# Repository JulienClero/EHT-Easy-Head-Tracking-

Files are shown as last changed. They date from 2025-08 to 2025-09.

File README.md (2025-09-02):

# EHT (Easy Head Tracking)

A DIY head tracking system using ESP32 and MPU6050 for gaming and simulations, compatible with OpenTrack.

## 🎯 Features

- **3DOF Tracking**: Yaw, Pitch, Roll with gyroscope, accelerometer and magnetometer
- **WiFi Transmission**: Real-time UDP data streaming
- **Complementary Filter**: Eliminates drift on pitch/roll
- **Start Up Yaw Calibartion**: Minimizes yaw drift
- **Low Latency**: Less than 20ms end-to-end
- **OpenTrack Compatible**: Plug & play with games and simulators

## 🔧 Components

### Current Version (v1.0)
- **ESP32** (DevKit v1 or similar) - ~$8
- **MPU6050** (accelerometer + gyroscope) - ~$3
- **4 jumper wires** female-female - ~$2
- **Case/mount** (3D printing recommended) - ~$2

### Future Version (v2.0) - In Development
- **ESP32-S3 N4** - ~$3.8 (JLCPCB)
- **ICM-20948** (9-axis, accelerometer + gyroscope + magnetometer) - ~$4.5
- **EHT Custom PCB** (currently being designed)
- **Li-Ion Battery** (500-1000mAh)
- **Charging Circuit** (integrated PCB)
- **ON/OFF Switch**
- **Custom Case** (3D printed) - <$1

## 📐 Wiring Diagram

### Version v1.0 (Prototype)
```
ESP32          MPU6050
-----          -------
3.3V    ---    VCC
GND     ---    GND
GPIO21  ---    SDA
GPIO22  ---    SCL
```

### Version v2.0 (Custom PCB)
*Detailed schematic available with custom PCB*

## 🚀 Installation

### 1. Prepare Environment
```bash
# Install Arduino IDE
# Add ESP32 support:
# File > Preferences > Additional Board Manager URLs
# https://dl.espressif.com/dl/package_esp32_index.json
```

### 2. Configure Code
```cpp
// Modify these variables in the code:
const char* ssid     = "YOUR_WIFI";
const char* password = "YOUR_PASSWORD";
IPAddress pcIP(192, 168, 1, XXX);  // Your PC IP
```

### 3. Flash ESP32
- Select board: `ESP32 Dev Module`
- Select serial port
- Make modifications to the code : Fill in your wifi ssid, password and your PC's IP adress (2. Configure Code)
- Compile and upload

## 🎮 OpenTrack Configuration

### 1. Install OpenTrack
Download from: https://github.com/opentrack/opentrack/releases

### 2. Configuration
1. **Input**: `UDP over network`
   - Port: `4242`
   - Bind address: `0.0.0.0`

2. **Output**: Choose according to your game
   - `freetrack 2.0 Enhanced` (most games)
   - `TrackIR` (for compatible games)

3. **Mapping**: Adjust to your preferences

### 3. Use
- Switch on your EHT
- Stay still while it calibrates (10 sec default)
- Start OpenTrack
- Click "Start"
- You should see the octopus move with your head

## 📊 Performance

- **Frequency**: 100Hz (10ms per sample)
- **Total Latency**: < 20ms
- **Accuracy**: ±1° (pitch/roll), ±2° (yaw)
- **Drift**: None on pitch/roll, slight on yaw

## 🔧 Advanced Settings (v1.0)

### Sensitivity Adjustment
```cpp
// In code, final lines:
headData[0] = yaw * 2.0;   // Multiply for more sensitivity
headData[1] = pitch * 3.0;
headData[2] = roll * 3.0;
```

### Complementary Filter
```cpp
const float alpha = 0.99f;  // 0.95-0.99 recommended
// Closer to 1.0 = more responsive but more noise
// Closer to 0.9 = more stable but less responsive
```

## 🛠️ Troubleshooting

### WiFi Connection Issues
- Check SSID/password
- Verify ESP32 is on same network
- Restart router if necessary

### Angle Drift
- **Pitch/Roll**: No drift (complementary filter)
- **Yaw**: Normal drift without magnetometer
- Solution: Recalibrate with `Ctrl+Home` in OpenTrack

### Erratic Data
- Check I2C connections
- Add decoupling capacitors if needed
- Verify stable 3.3V power supply

### High Latency
- Reduce `LOOP_INTERVAL_MS` (watch CPU load)
- Use 5GHz WiFi if possible
- Disable WiFi sleep mode

## 🤝 Contributing

Contributions are welcome! Feel free to:
- Report bugs
- Suggest improvements
- Share hardware modifications
- Add support for more games

## 📄 License

See the `LICENSE` file for details.

## 🎮 Tested Games

- ✅ **DCS World** (freetrack)
- ✅ **Star Citizen** (freetrack)

## 🔮 Roadmap

### Version 1.0 (Current) ✅
- [x] 3DOF tracking (Yaw, Pitch, Roll)
- [x] WiFi UDP transmission
- [x] Complementary filter
- [x] Yaw Calibration
- [x] OpenTrack compatibility

### Version 2.0 (Planned)
- [ ] **EHT Custom PCB** - Compact and professional design
- [ ] **Magnetometer support** - Eliminates yaw drift
- [ ] **Integrated battery** - 8-12h autonomy
- [ ] **USB-C charging circuit** - Fast charging
- [ ] **Status LEDs or Small OLED Screen** - Battery, WiFi, tracking

---

**⚠️ Important**: This project is for personal use. Please respect the terms of use of games and simulators.

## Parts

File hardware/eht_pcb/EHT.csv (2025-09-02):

Reference | Qty | Value | DNP | Exclude from BOM | Exclude from Board | Footprint | Datasheet
BT1 | 1 | Battery_Cell |  |  |  |  | ~
C1,CIN2,COUT2 | 3 | 1uF |  |  |  | Capacitor_SMD:C_0603_1608Metric | ~
C2,CEN1,C_BP1,C_BP2,C_BP3,C_BP4,C_BP5,C_BP6,C_BP7 | 9 | 0.1uF |  |  |  | Capacitor_SMD:C_0603_1608Metric | ~
CBAT1 | 1 | 4.7uF |  |  |  | Capacitor_SMD:C_0603_1608Metric | ~
CIN1,COUT1 | 2 | 22uF |  |  |  | Capacitor_SMD:C_0603_1608Metric | ~
D1 | 1 | PTVS5V0Z1USK |  |  |  | Diode_SMD:Nexperia_DSN1608-2_1.6x0.8mm | https://assets.nexperia.com/documents/data-sheet/PTVS5V0Z1USK.pdf
D2,D3 | 2 | PESD3V3U1UL |  |  |  | Diode_SMD:D_SOD-882 | https://assets.nexperia.com/documents/data-sheet/PESD3V3U1UL.pdf
DCHG1,DPGOOD1 | 2 | LED |  |  |  | LED_SMD:LED_0805_2012Metric | ~
H1,H2,H3,H4 | 4 | MountingHole |  | Exclure de la Liste du Matériel |  | MountingHole:MountingHole_2.2mm_M2 | ~
J1 | 1 | Type-C Connector |  |  |  | Connector_USB:USB_C_Receptacle_GCT_USB4105-xx-A_16P_TopMnt_Horizontal | https://www.usb.org/sites/default/files/documents/usb_type-c.zip
R1 | 1 | R1.13k |  |  |  | Resistor_SMD:R_0603_1608Metric | ~
R2 | 1 | R1.18k |  |  |  | Resistor_SMD:R_0603_1608Metric | ~
R3 | 1 | R10k |  |  |  | Resistor_SMD:R_0603_1608Metric | ~
R4,R5,REN1 | 3 | R1k |  |  |  | Resistor_SMD:R_0603_1608Metric | ~
R_CC1,R_CC2 | 2 | R5.1k |  |  |  | Resistor_SMD:R_0603_1608Metric | ~
SW1 | 1 | SW_Push |  |  |  | Button_Switch_THT:SW_PUSH_1P1T_6x3.5mm_H4.3_APEM_MJTP1243 | ~
SW2 | 1 | SW |  |  |  | Button_Switch_SMD:SW_DIP_SPSTx01_Slide_Copal_CHS-01A_W5.08mm_P1.27mm_JPin | ~
U2 | 1 | ICM-20948 |  |  |  | Sensor_Motion:InvenSense_QFN-24_3x3mm_P0.4mm | http://www.invensense.com/wp-content/uploads/2016/06/DS-000189-ICM-20948-v1.3.pdf
U3 | 1 | BQ24074 |  |  |  | Package_DFN_QFN:VQFN-16-1EP_3x3mm_P0.5mm_EP1.6x1.6mm | http://www.ti.com/lit/ds/symlink/bq24074.pdf
U4 | 1 | TLV70019_SOT23-5 |  |  |  | Package_TO_SOT_SMD:SOT-23-5 | http://www.ti.com/lit/ds/symlink/tlv700.pdf
U5 | 1 | TXB0104D |  |  |  | Package_SO:SOIC-14_3.9x8.7mm_P1.27mm | http://www.ti.com/lit/ds/symlink/txb0104.pdf
U6 | 1 | AMS1117-3.3 |  |  |  | Package_TO_SOT_SMD:SOT-223-3_TabPin2 | http://www.advanced-monolithic.com/pdf/ds1117.pdf
U7 | 1 | ESP32-S3-WROOM-1 |  |  |  | RF_Module:ESP32-S3-WROOM-1 | https://www.espressif.com/sites/default/files/documentation/esp32-s3-wroom-1_wroom-1u_datasheet_en.pdf

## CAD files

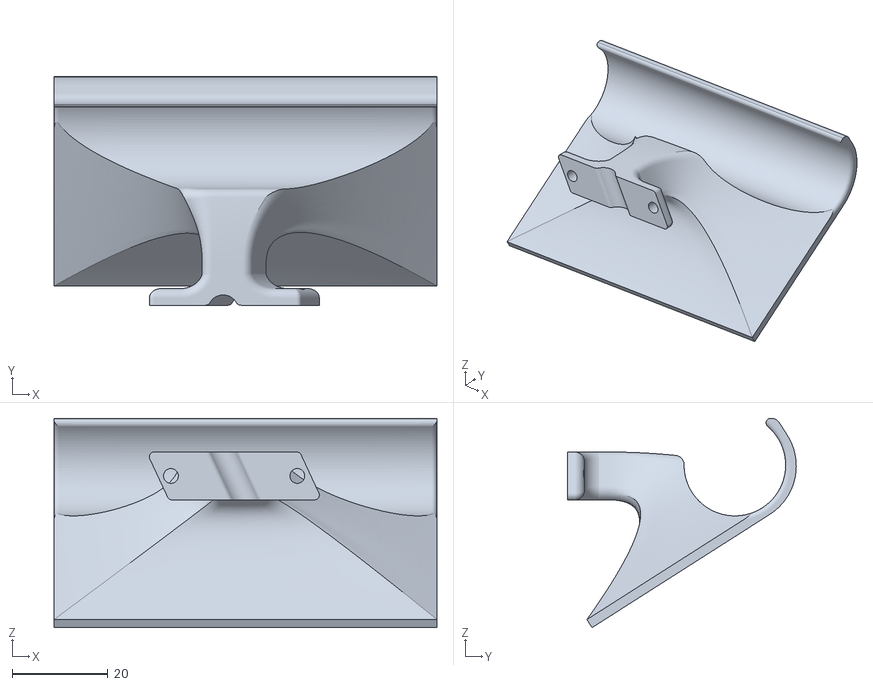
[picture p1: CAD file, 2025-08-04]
hardware/3d_models/EHT_V1_LogitechG935_Mount.stl
80.0 x 47.7 x 43.7

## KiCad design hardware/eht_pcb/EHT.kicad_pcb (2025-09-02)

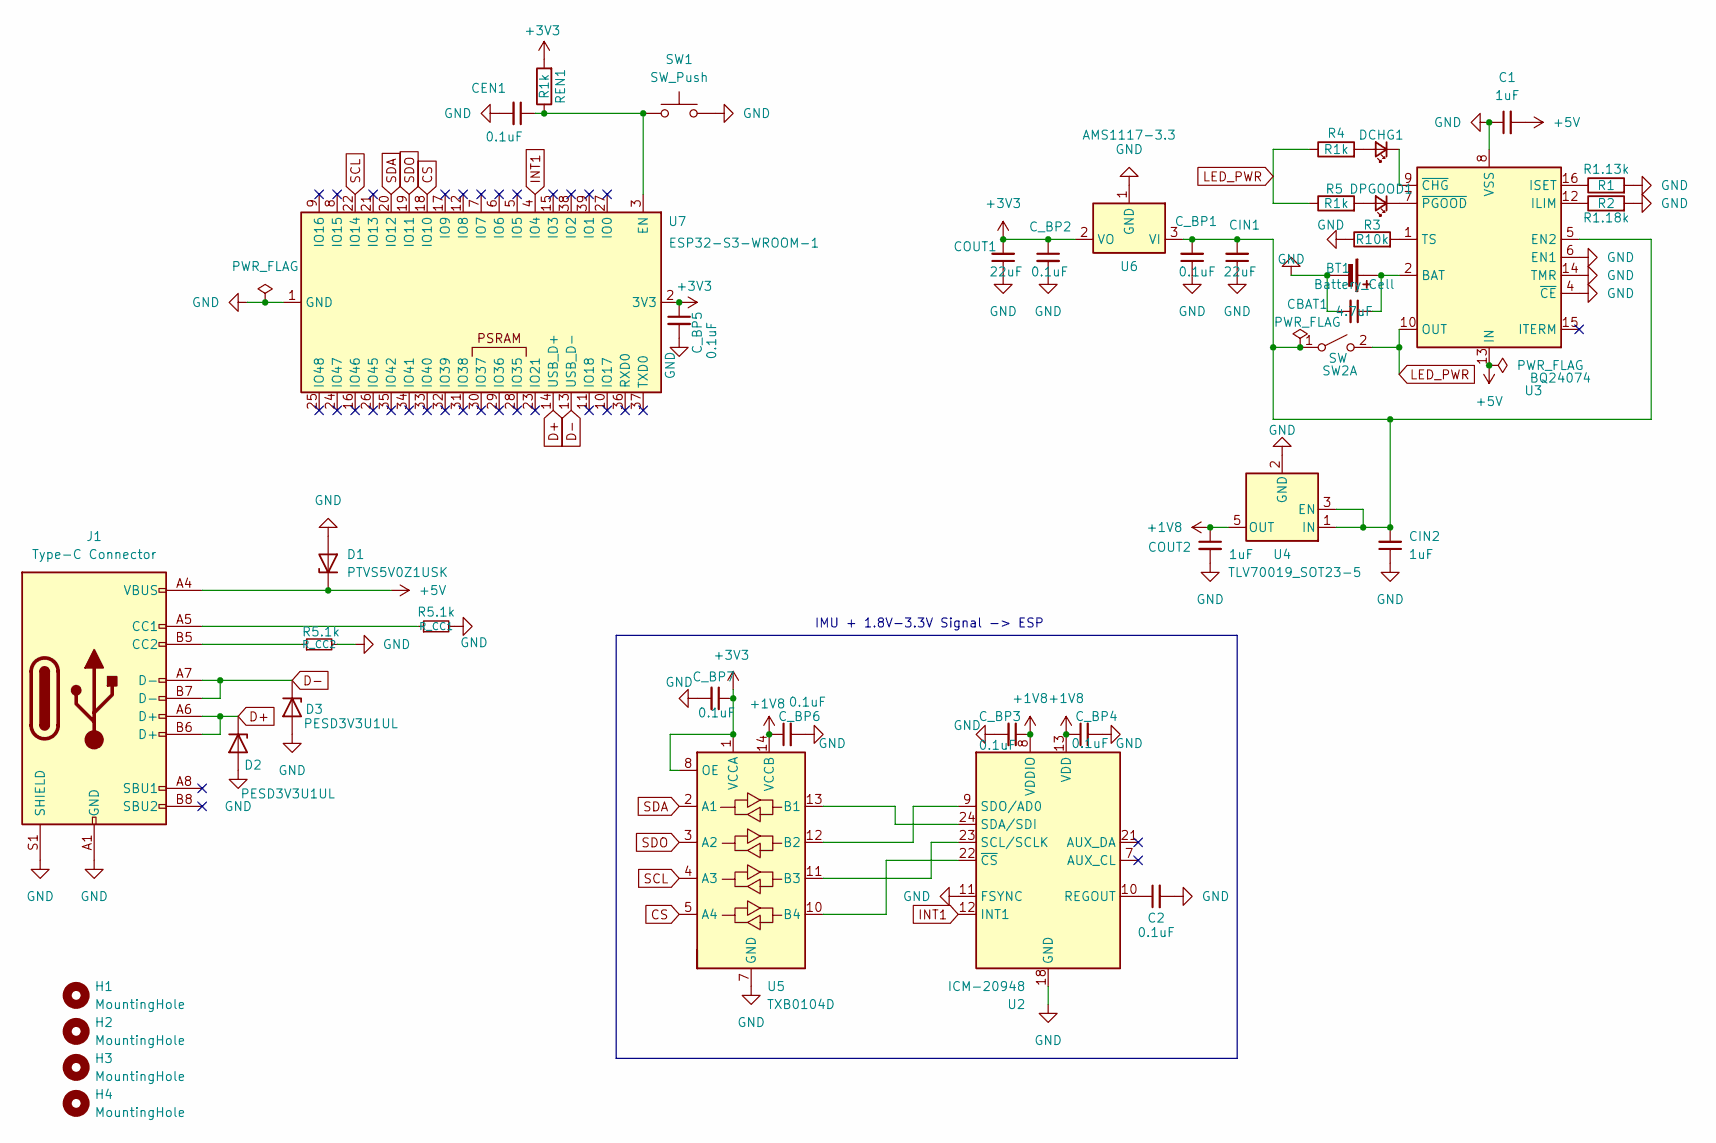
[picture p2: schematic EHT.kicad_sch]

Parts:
BT1: Battery_Cell
C1: 1uF; C_0603_1608Metric
C2: 0.1uF; C_0603_1608Metric
CBAT1: 4.7uF; C_0603_1608Metric
CEN1: 0.1uF; C_0603_1608Metric
CIN1: 22uF; C_0603_1608Metric
CIN2: 1uF; C_0603_1608Metric
COUT1: 22uF; C_0603_1608Metric
COUT2: 1uF; C_0603_1608Metric
C_BP1, C_BP2, C_BP3, C_BP4, C_BP5, C_BP6, C_BP7: 0.1uF; C_0603_1608Metric
D1: PTVS5V0Z1USK; Nexperia_DSN1608-2_1.6x0.8mm
D2, D3: PESD3V3U1UL; D_SOD-882
DCHG1: LED; LED_0805_2012Metric
DPGOOD1: LED; LED_0805_2012Metric
H1, H2, H3, H4: MountingHole; MountingHole_2.2mm_M2
J1: Type-C Connector; USB_C_Receptacle_GCT_USB4105-xx-A_16P_TopMnt_Horizontal
R1: R1.13k; R_0603_1608Metric
R2: R1.18k; R_0603_1608Metric
R3: R10k; R_0603_1608Metric
R4, R5: R1k; R_0603_1608Metric
REN1: R1k; R_0603_1608Metric
R_CC1, R_CC2: R5.1k; R_0603_1608Metric
SW1: SW_Push; SW_PUSH_1P1T_6x3.5mm_H4.3_APEM_MJTP1243
SW2: SW; SW_DIP_SPSTx01_Slide_Copal_CHS-01A_W5.08mm_P1.27mm_JPin
U2: ICM-20948; InvenSense_QFN-24_3x3mm_P0.4mm
U3: BQ24074; VQFN-16-1EP_3x3mm_P0.5mm_EP1.6x1.6mm
U4: TLV70019_SOT23-5; SOT-23-5
U5: TXB0104D; SOIC-14_3.9x8.7mm_P1.27mm
U6: AMS1117-3.3; SOT-223-3_TabPin2
U7: ESP32-S3-WROOM-1

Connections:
+1V8: COUT2.1, C_BP3.1, C_BP4.1, C_BP6.1, U2.8 (VDDIO), U2.13 (VDD), U4.5 (OUT), U5.14 (VCCB)
+3V3: COUT1.2, C_BP2.1, C_BP5.1, C_BP7.1, REN1.2, U5.1 (VCCA), U5.8 (OE), U6.2 (VO), U7.2 (3V3)
+5V: C1.2, D1.1 (K), J1.A4 (VBUS), J1.A9 (VBUS), J1.B4 (VBUS), J1.B9 (VBUS), U3.13 (IN)
CS: U5.5 (A4), U7.18 (IO10)
D+: D2.1 (K), J1.A6 (D+), J1.B6 (D+), U7.14 (USB_D+)
D-: D3.1 (K), J1.A7 (D-), J1.B7 (D-), U7.13 (USB_D-)
GND: BT1.2 (-), C1.1, C2.2, CBAT1.2, CEN1.2, CIN1.1, CIN2.1, COUT1.1, COUT2.2, C_BP1.1, C_BP2.2, C_BP3.2, C_BP4.2, C_BP5.2, C_BP6.2, C_BP7.2, D1.2 (A), D2.2 (A), D3.2 (A), J1.A1 (GND), J1.A12 (GND), J1.B1 (GND), J1.B12 (GND), J1.S1 (SHIELD), R1.2, R2.2, R3.1, R_CC1.2, R_CC2.2, SW1.2, U2.11 (FSYNC), U2.18 (GND), U2.20 (GND), U3.4 (~CE), U3.6 (EN1), U3.8 (VSS), U3.14 (TMR), U3.17 (VSS), U4.2 (GND), U5.7 (GND), U6.1 (GND), U7.1 (GND), U7.40 (GND), U7.41 (GND); also elsewhere on the board
INT1: U2.12 (INT1), U7.4 (IO4)
LED_PWR: R4.1, R5.1, SW2.2 (B), U3.10 (OUT), U3.11 (OUT)
unnamed 9: BT1.1 (+), CBAT1.1, U3.2 (BAT), U3.3 (BAT); also elsewhere on the board
unnamed: DCHG1.2 (A), R4.2
unnamed: DCHG1.1 (K), U3.9 (~CHG)
unnamed: DPGOOD1.2 (A), R5.2
unnamed: DPGOOD1.1 (K), U3.7 (~PGOOD)
unnamed: J1.A5 (CC1), R_CC1.1
unnamed: J1.B5 (CC2), R_CC2.1
unnamed: CIN1.2, CIN2.2, C_BP1.2, SW2.1 (A), U3.5 (EN2), U4.1 (IN), U4.3 (EN), U6.3 (VI)
unnamed: C2.1, U2.10 (REGOUT)
unnamed: U2.23 (SCL/SCLK), U5.11 (B3)
unnamed: U2.24 (SDA/SDI), U5.13 (B1)
unnamed: U2.9 (SDO/AD0), U5.12 (B2)
unnamed: U2.22 (~CS), U5.10 (B4)
unnamed: R2.1, U3.12 (ILIM)
unnamed: R1.1, U3.16 (ISET)
unnamed: R3.2, U3.1 (TS)
unnamed: CEN1.1, REN1.1, SW1.1, U7.3 (EN)
SCL: U5.4 (A3), U7.22 (IO14)
SDA: U5.2 (A1), U7.20 (IO12)
SDO: U5.3 (A2), U7.19 (IO11)

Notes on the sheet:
IMU + 1.8V-3.3V Signal -> ESP

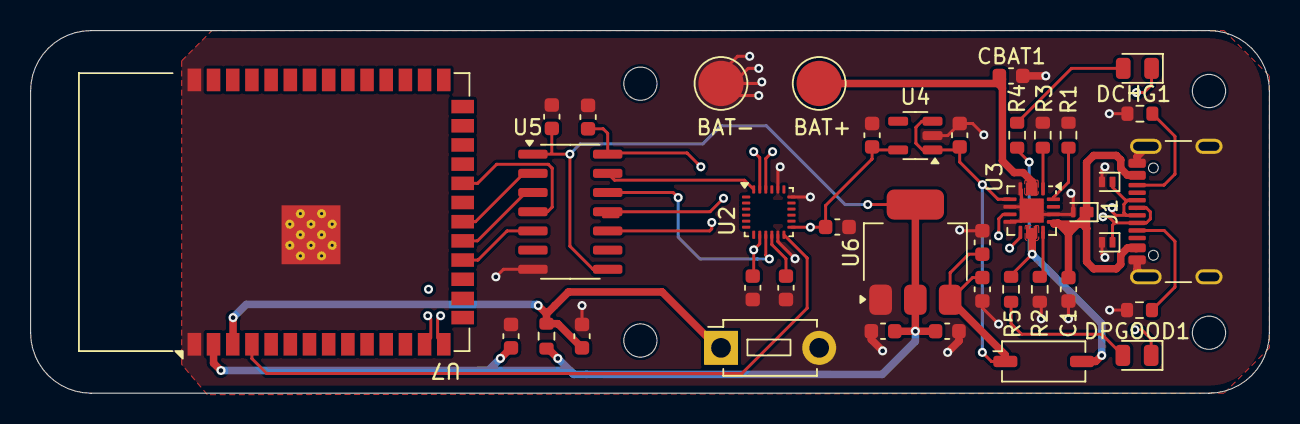
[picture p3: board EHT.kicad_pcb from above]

Board: 4 copper layers, 82.0 x 24.0 mm, 43 parts (0 on the bottom side), 29 nets.

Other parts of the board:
BAT+: TestPoint_Pad_D3.0mm
BAT-: TestPoint_Pad_D3.0mm

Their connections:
GND: BAT-.1; also elsewhere on the board
unnamed 9: BAT+.1; also elsewhere on the board

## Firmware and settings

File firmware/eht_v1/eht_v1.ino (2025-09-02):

#include <Wire.h>
#include <WiFi.h>
#include <WiFiUdp.h>

// ======= Réseau =======
const char* ssid     = "Livebox-197A";
const char* password = "62AB114F8D346586595ED49934";
IPAddress pcIP(192, 168, 1, 21);
const uint16_t pcPort   = 4242;
WiFiUDP udp;
const uint16_t localPort = 4242;

// ======= MPU6050 =======
#define MPU_ADDR       0x68
#define PWR_MGMT_1     0x6B
#define ACCEL_XOUT_H   0x3B
#define GYRO_XOUT_H    0x43

// Variables de tracking (thread-safe avec mutex)
portMUX_TYPE angleMux = portMUX_INITIALIZER_UNLOCKED;
double headData[3];
volatile float yaw = 0, pitch = 0, roll = 0;

// Paramètres du filtre complémentaire
const float alpha = 0.98f;

// Variables pour calibration automatique du drift
float drift_sum = 0.0f;
int drift_samples = 0;
float drift_correction = 0.0f;
bool calibration_complete = false;
unsigned long calibration_start = 0;
const unsigned long CALIBRATION_DURATION = 10000; // 10 secondes

// Gestion d'erreurs I2C
int i2c_error_count = 0;
const int MAX_I2C_ERRORS = 3;
bool mpu_initialized = false;

// Queue pour communication inter-core
QueueHandle_t sensorQueue;
struct SensorData {
  float ax_g, ay_g, az_g;
  float gx_dps, gy_dps, gz_dps;
  unsigned long timestamp;
};

// I2C write avec gestion d'erreur
bool writeByte(uint8_t addr, uint8_t reg, uint8_t val) {
  Wire.beginTransmission(addr);
  Wire.write(reg);
  Wire.write(val);
  uint8_t error = Wire.endTransmission();
  
  if (error != 0) {
    i2c_error_count++;
    return false;
  }
  return true;
}

// I2C read avec timeout
bool readBytes(uint8_t addr, uint8_t reg, uint8_t len, uint8_t* buf) {
  Wire.beginTransmission(addr);
  Wire.write(reg);
  if (Wire.endTransmission(false) != 0) {
    i2c_error_count++;
    return false;
  }
  
  if (Wire.requestFrom(addr, len) != len) {
    i2c_error_count++;
    return false;
  }
  
  for (uint8_t i = 0; i < len; i++) {
    buf[i] = Wire.read();
  }
  return true;
}

// Initialisation MPU6050
bool initMPU() {
  if (!writeByte(MPU_ADDR, PWR_MGMT_1, 0x80)) return false; 
  delay(50);
  if (!writeByte(MPU_ADDR, PWR_MGMT_1, 0x00)) return false; 
  delay(10);
  
  // Configuration optimisée pour la précision
  if (!writeByte(MPU_ADDR, 0x1A, 0x01)) return false; // DLPF = 188Hz
  if (!writeByte(MPU_ADDR, 0x1B, 0x00)) return false; // Gyro ±250°/s
  if (!writeByte(MPU_ADDR, 0x1C, 0x00)) return false; // Accel ±2g
  if (!writeByte(MPU_ADDR, 0x19, 0x07)) return false; // Sample rate = 125Hz
  
  return true;
}

// Réinitialisation I2C
void resetI2C() {
  Wire.end();
  delay(30);
  Wire.begin(10, 11);
  Wire.setClock(400000);
  delay(30);
  
  mpu_initialized = initMPU();
  i2c_error_count = 0;
}

// Runge-Kutta 2ème ordre pour l'intégration du yaw
float rungeKutta2_yaw(float current_yaw, float gz_dps, float dt) {
  // K1 = f(t, y) = gz_dps
  float k1 = gz_dps;
  
  // K2 = f(t + dt/2, y + k1*dt/2) 
  // Pour une vitesse angulaire constante sur dt, k2 = k1
  float k2 = gz_dps;
  
  // Intégration RK2
  return current_yaw + dt * (k1 + k2) / 2.0f;
}

// Filtre complémentaire avec Runge-Kutta pour le yaw
void updateAngles(float gx_dps, float gy_dps, float gz_dps, float ax_g, float ay_g, float az_g, float dt) {
  // Phase de calibration du drift (10 secondes)
  if (!calibration_complete) {
    drift_sum += gz_dps;
    drift_samples++;
    
    // Vérifier si la calibration est terminée
    if (millis() - calibration_start >= CALIBRATION_DURATION) {
      drift_correction = drift_sum / drift_samples;
      calibration_complete = true;
      Serial.printf("Calibration terminée - Drift correction: %.4f deg/s\n", drift_correction);
    }
    return; // Ne pas calculer les angles pendant la calibration
  }
  
  // Calcul des angles depuis l'accéléromètre
  float pitch_acc = atan2(-ax_g, sqrt(ay_g*ay_g + az_g*az_g)) * 180.0f / PI;
  float roll_acc = atan2(ay_g, az_g) * 180.0f / PI;
  
  // Filtre complémentaire pour pitch et roll
  pitch = alpha * (pitch + gy_dps * dt) + (1.0f - alpha) * pitch_acc;
  roll = alpha * (roll + gx_dps * dt) + (1.0f - alpha) * roll_acc;
  
  gz_dps = gz_dps - drift_correction;
  // Intégration Runge-Kutta 2ème ordre pour le yaw
  yaw = rungeKutta2_yaw(yaw, gz_dps, dt);
  
  // Normalisation du yaw
  if (yaw > 180.0f) yaw -= 360.0f;
  if (yaw < -180.0f) yaw += 360.0f;
}

// CORE 0: Acquisition des données senseur (haute priorité)
void sensorTask(void *pvParameters) {
  for(;;) {
    // Reset I2C si trop d'erreurs
    if (i2c_error_count > MAX_I2C_ERRORS) {
      resetI2C();
      vTaskDelay(pdMS_TO_TICKS(100));
      continue;
    }

    if (!mpu_initialized) {
      vTaskDelay(pdMS_TO_TICKS(100));
      continue;
    }

    // Lecture des données MPU6050
    uint8_t accel_buf[6], gyro_buf[6];
    bool accel_ok = readBytes(MPU_ADDR, ACCEL_XOUT_H, 6, accel_buf);
    bool gyro_ok = readBytes(MPU_ADDR, GYRO_XOUT_H, 6, gyro_buf);

    if (!accel_ok || !gyro_ok) {
      vTaskDelay(pdMS_TO_TICKS(1));
      continue;
    }

    // Conversion des données
    int16_t raw_ax = (accel_buf[0] << 8) | accel_buf[1];
    int16_t raw_ay = (accel_buf[2] << 8) | accel_buf[3];
    int16_t raw_az = (accel_buf[4] << 8) | accel_buf[5];
    
    int16_t raw_gx = (gyro_buf[0] << 8) | gyro_buf[1];
    int16_t raw_gy = (gyro_buf[2] << 8) | gyro_buf[3];
    int16_t raw_gz = (gyro_buf[4] << 8) | gyro_buf[5];

    // Préparation des données pour le calcul
    SensorData data;
    data.ax_g = raw_ax / 16384.0f;
    data.ay_g = raw_ay / 16384.0f;
    data.az_g = raw_az / 16384.0f;
    data.gx_dps = raw_gx / 131.0f;
    data.gy_dps = raw_gy / 131.0f;
    data.gz_dps = raw_gz / 131.0f;
    data.timestamp = millis();

    // Envoi vers le core de calcul (non-bloquant)
    xQueueSend(sensorQueue, &data, 0);

    // Fréquence ~500Hz pour l'acquisition
    vTaskDelay(pdMS_TO_TICKS(2));
  }
}

// CORE 1: Calcul et transmission (loop principal)
void setup() {
  Serial.begin(115200);
  
  // I2C setup
  Wire.begin(10, 11);
  Wire.setClock(400000);
  
  // Initialisation MPU6050
  mpu_initialized = initMPU();
  if (!mpu_initialized) {
    Serial.println("MPU6050 init failed!");
  } else {
    Serial.println("MPU6050 OK - RK2 Simple");
  }

  // Wi-Fi
  WiFi.begin(ssid, password);
  WiFi.setSleep(false);

  unsigned long wifiStart = millis();
  while (WiFi.status() != WL_CONNECTED && millis() - wifiStart < 10000) {
    delay(500);
    Serial.print(".");
  }
  
  if (WiFi.status() == WL_CONNECTED) {
    Serial.println("\nWiFi OK");
    udp.begin(localPort);
  } else {
    Serial.println("\nWiFi FAILED");
  }

  // Création de la queue inter-core
  sensorQueue = xQueueCreate(10, sizeof(SensorData));
  
  // Lancement de la tâche d'acquisition sur le Core 0
  xTaskCreatePinnedToCore(
    sensorTask,     // Fonction
    "SensorTask",   // Nom
    4096,          // Stack size
    NULL,          // Paramètres
    2,             // Priorité (haute)
    NULL,          // Handle
    0              // Core 0
  );

  Serial.println("Dual-core setup OK");
  
  // Démarrage de la calibration du drift
  calibration_start = millis();
  Serial.println("Calibration du drift en cours (10s)... Ne pas bouger le capteur!");
}

void loop() {
  static unsigned long lastTime = millis();
  SensorData data;
  
  // Réception des données du core d'acquisition
  if (xQueueReceive(sensorQueue, &data, pdMS_TO_TICKS(5)) == pdPASS) {
    
    // Calcul du temps écoulé
    float dt = (data.timestamp - lastTime) / 1000.0f;
    dt = constrain(dt, 0.001f, 0.1f); // Limitation pour éviter les valeurs aberrantes
    lastTime = data.timestamp;

    // Mise à jour des angles avec protection thread-safe
    portENTER_CRITICAL(&angleMux);
    updateAngles(data.gx_dps, data.gy_dps, data.gz_dps, 
                 data.ax_g, data.ay_g, data.az_g, dt);
    
    // Copie des angles pour transmission
    headData[0] = yaw * 2.0;
    headData[1] = pitch * 3.0;
    headData[2] = roll * 3.0;
    portEXIT_CRITICAL(&angleMux);

    // Debug périodique
    static unsigned long lastDebug = 0;
    if (millis() - lastDebug > 1000) {
      if (calibration_complete) {
        Serial.printf("Yaw: %.2f Pitch: %.2f Roll: %.2f | dt: %.3f | Drift: %.4f\n", 
                      yaw, pitch, roll, dt, drift_correction);
      } else {
        unsigned long remaining = CALIBRATION_DURATION - (millis() - calibration_start);
        Serial.printf("Calibration... %lu ms restantes\n", remaining);
      }
      lastDebug = millis();
    }
  }

  // Envoi UDP seulement après calibration
  static unsigned long lastUdp = 0;
  if (calibration_complete && millis() - lastUdp > 10) {
    if (udp.beginPacket(pcIP, pcPort)) {
      udp.write((uint8_t*)headData, sizeof(headData));
      udp.endPacket();
    }
    lastUdp = millis();
  }

  // Petite pause pour ne pas surcharger
  delay(1);
}

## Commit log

2025-08-04 Update eht_v1.ino
    Updated low level approach using both cores of the ESP32 chip and a custom MPU6050 interface (Because it is not realy an MPU6050 and libraries don't work, you can change this part and use libraries).
2025-08-04 Added EHT MOUNT for Logitech G935
    A basic stl file of a 3d printable mount for EHT adapted ont my G935 headset.
    [EHT_V1_LogitechG935_Mount.stl]
2025-09-02 Added documentation, Circuit diagram, PCB Gerber...
    [EHT-B_Cu.gbr, EHT-B_Mask.gbr, EHT-B_Paste.gbr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]
2025-09-02 Added, PCB files and documentation
    [EHT-B_Cu.gbr, EHT-B_Mask.gbr, EHT-B_Paste.gbr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]
